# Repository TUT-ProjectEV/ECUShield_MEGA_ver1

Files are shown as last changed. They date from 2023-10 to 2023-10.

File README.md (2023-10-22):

# ECUShield_MEGA_ver1

## Overview
- メインECUのシールド
- 2023年度10月時点で使用

## Requirement
### Development
- Kicad 7.0
### Boards
- Arduino Mega
### Libraries

## Usage

## Features

## Reference
- [ECUShield_MEGA_ver1](https://github.com/ST04-tkmr/KicadProjects_EVProject/tree/main/ECUShield_MEGA_ver1) より

## Author
- Takamura
    - [GitHub](https://github.com/ST04-tkmr)

## License
- Copyright (c) 2023 東京工科大学 ProjectEV [Released under the MIT license](https://github.com/TUT-ProjectEV/ECUShield_MEGA_ver1/blob/main/LICENSE)

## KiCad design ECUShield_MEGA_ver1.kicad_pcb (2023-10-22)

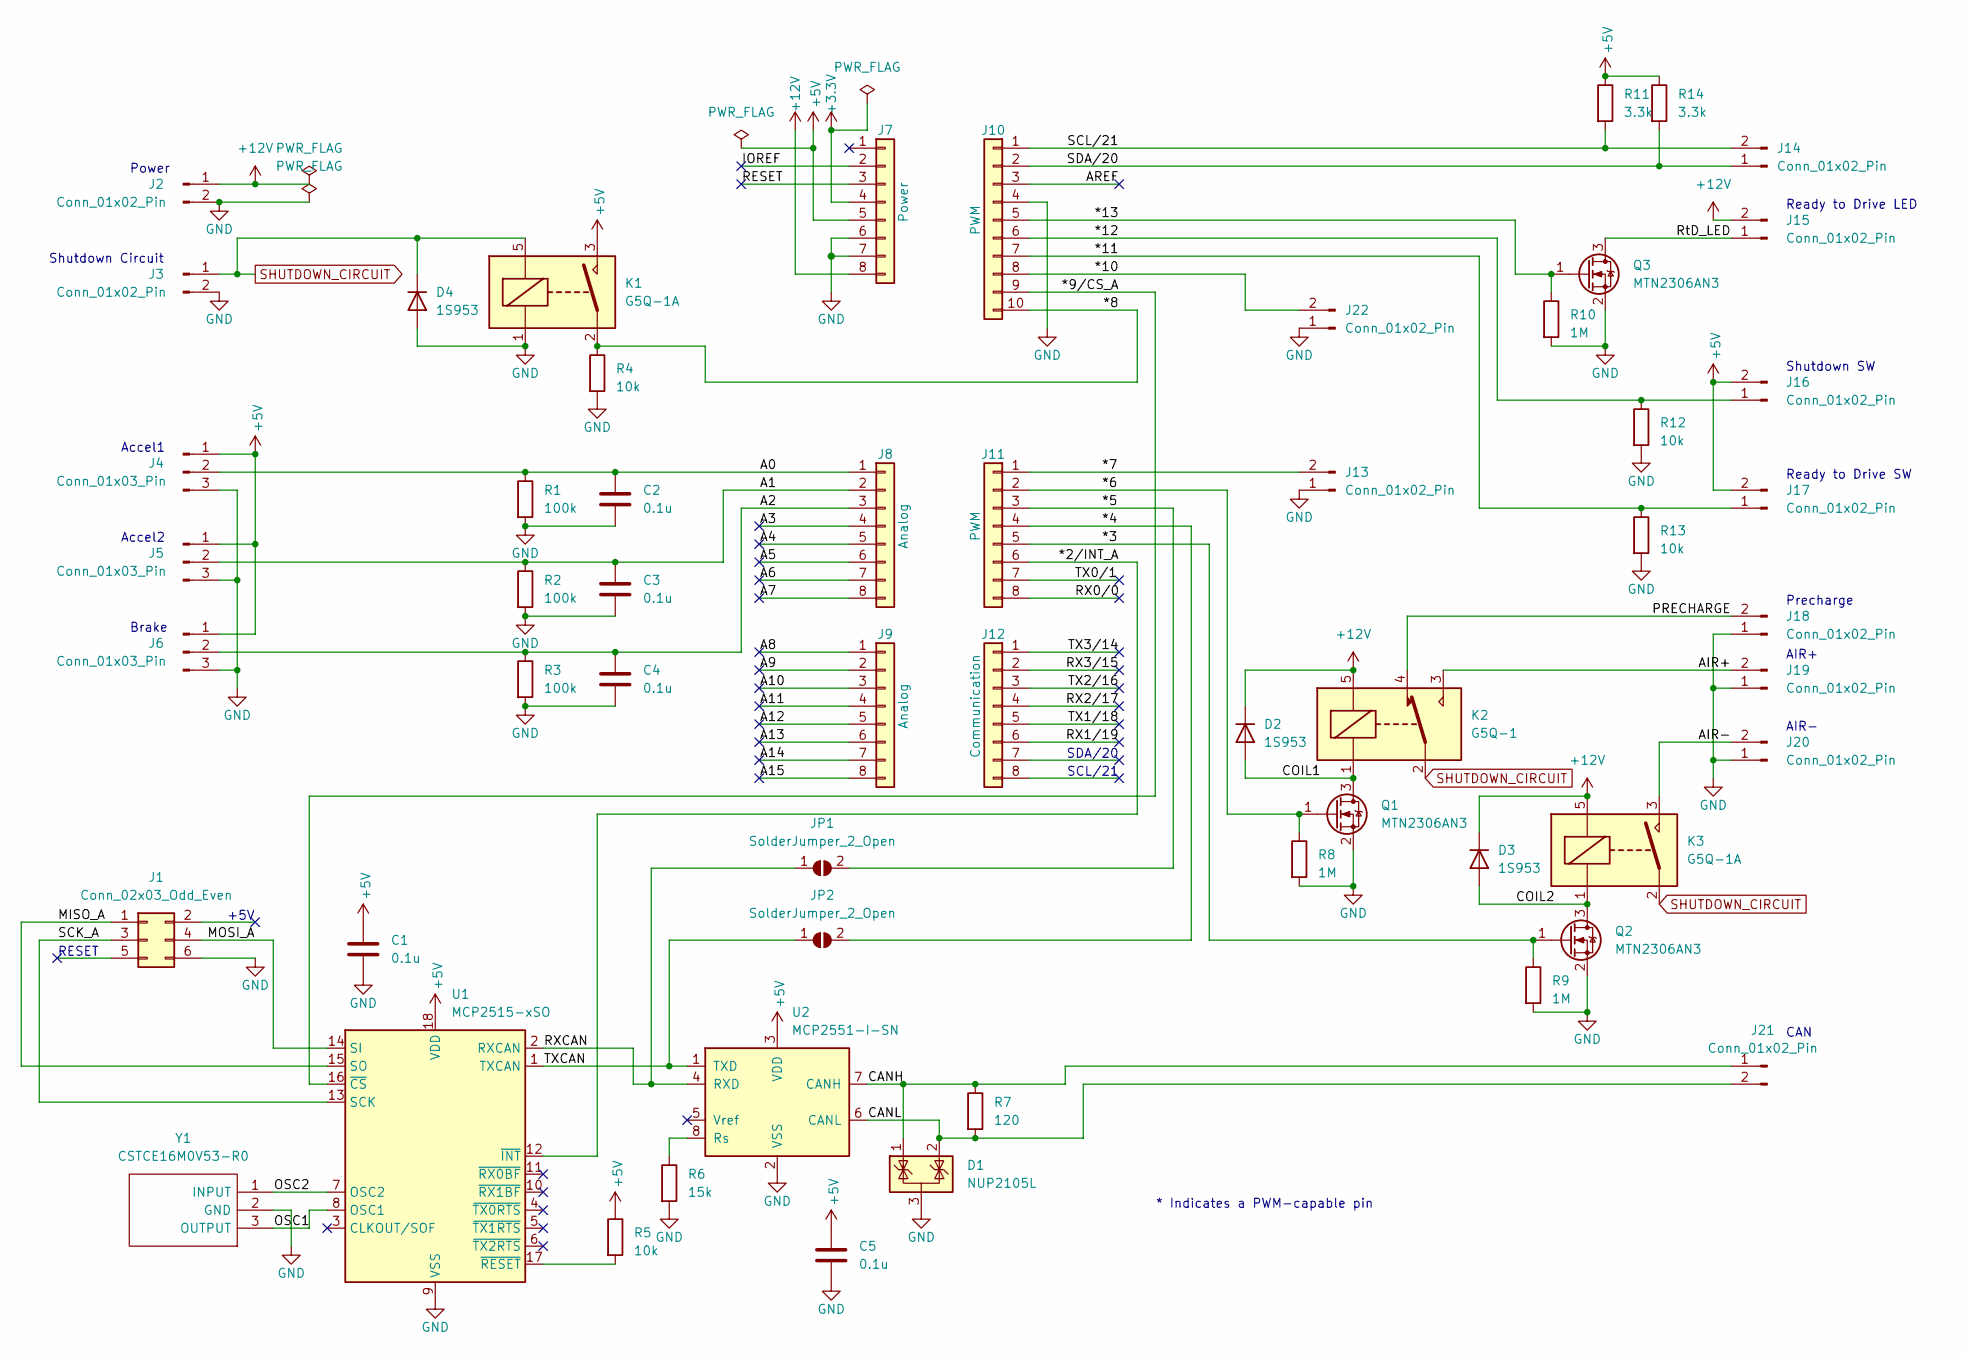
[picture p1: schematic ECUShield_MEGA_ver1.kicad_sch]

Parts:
C1, C2, C3, C4, C5: 0.1u; C_0603_1608Metric
D1: NUP2105L; SOT-23
D2, D3, D4: 1S953; D_DO-35_SOD27_P7.62mm_Horizontal
J1: Conn_02x03_Odd_Even; PinSocket_2x03_P2.54mm_Vertical
J2, J3, J13, J14, J15, J16, J17, J18, J19, J20, J21, J22: Conn_01x02_Pin; JST_XH_B2B-XH-A_1x02_P2.50mm_Vertical
J4, J5, J6: Conn_01x03_Pin; JST_XH_B3B-XH-A_1x03_P2.50mm_Vertical
J7: Power; PinSocket_1x08_P2.54mm_Vertical
J8, J9: Analog; PinSocket_1x08_P2.54mm_Vertical
J10: PWM; PinSocket_1x10_P2.54mm_Vertical
J11: PWM; PinSocket_1x08_P2.54mm_Vertical
J12: Communication; PinSocket_1x08_P2.54mm_Vertical
JP1, JP2: SolderJumper_2_Open; SolderJumper-2_P1.3mm_Open_RoundedPad1.0x1.5mm
K1, K3: G5Q-1A; Relay_SPST_Omron-G5Q-1A
K2: G5Q-1; Relay_SPDT_Omron-G5Q-1
Q1, Q2, Q3: MTN2306AN3; TSOT-23
R1, R2, R3: 100k; R_0603_1608Metric
R4, R5, R12, R13: 10k; R_0805_2012Metric
R6: 15k; R_0603_1608Metric
R7: 120; R_0603_1608Metric
R8, R9, R10: 1M; R_0603_1608Metric
R11, R14: 3.3k; R_0603_1608Metric
U1: MCP2515-xSO; SOIC-18W_7.5x11.6mm_P1.27mm
U2: MCP2551-I-SN; SOIC-8_3.9x4.9mm_P1.27mm
Y1: CSTCE16M0V53-R0; CSTCE16M0V53R0; Manufacturer_Part_Number CSTCE16M0V53-R0; Mouser Part Number 81-CSTCE16M0V53-R0

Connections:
+3.3V: J7.4
+5V: C1.1, C5.1, J4.1, J5.1, J6.1, J7.5, J16.2, J17.2, K1.3, R5.1, R11.1, R14.1, U1.18 (VDD), U2.3 (VDD)
+12V: D2.1 (K), D3.1 (K), J2.1, J7.8, J15.2, K2.5, K3.5
/*2/INT_A: J11.6, U1.12 (~INT)
/*3: J11.5, Q2.1 (G), R9.1
/*4: J11.4, JP2.2 (B)
/*5: J11.3, JP1.2 (B)
/*6: J11.2, Q1.1 (G), R8.1
/*7: J11.1, J13.2
/*8: J10.10, K1.2, R4.1
/*9/CS_A: J10.9, U1.16 (~CS)
/*10: J10.8, J22.2
/*11: J10.7, J17.1, R13.1
/*12: J10.6, J16.1, R12.1
/*13: J10.5, Q3.1 (G), R10.1
/A0: C2.1, J4.2, J8.1, R1.1
/A1: C3.1, J5.2, J8.2, R2.1
/A2: C4.1, J6.2, J8.3, R3.1
/A3: J8.4
/A4: J8.5
/A5: J8.6
/A6: J8.7
/A7: J8.8
/A8: J9.1
/A9: J9.2
/A10: J9.3
/A11: J9.4
/A12: J9.5
/A13: J9.6
/A14: J9.7
/A15: J9.8
/AIR+: J19.2, K2.3
/AIR-: J20.2, K3.3
/AREF: J10.3
/CANH: D1.1 (K), J21.1, R7.1, U2.7 (CANH)
/CANL: D1.2 (K), J21.2, R7.2, U2.6 (CANL)
/COIL1: D2.2 (A), K2.1, Q1.3 (D)
/COIL2: D3.2 (A), K3.1, Q2.3 (D)
/IOREF: J7.2
/MISO_A: J1.1, U1.15 (SO)
/MOSI_A: J1.4, U1.14 (SI)
/OSC1: U1.8 (OSC1), Y1.3 (OUTPUT)
/OSC2: U1.7 (OSC2), Y1.1 (INPUT)
/PRECHARGE: J18.2, K2.4
/RESET: J7.3
/RX0/0: J11.8
/RX1/19: J12.6
/RX2/17: J12.4
/RX3/15: J12.2
/RXCAN: JP1.1 (A), U1.2 (RXCAN), U2.4 (RXD)
/RtD_LED: J15.1, Q3.3 (D)
/SCK_A: J1.3, U1.13 (SCK)
/SCL/21: J10.1, J14.2, R11.2
/SDA/20: J10.2, J14.1, R14.2
/TX0/1: J11.7
/TX1/18: J12.5
/TX2/16: J12.3
/TX3/14: J12.1
/TXCAN: JP2.1 (A), U1.1 (TXCAN), U2.1 (TXD)
GND: C1.2, C2.2, C3.2, C4.2, C5.2, D1.3 (A), D4.2 (A), J1.6, J2.2, J3.2, J4.3, J5.3, J6.3, J7.6, J7.7, J10.4, J13.1, J18.1, J19.1, J20.1, J22.1, K1.1, Q1.2 (S), Q2.2 (S), Q3.2 (S), R1.2, R2.2, R3.2, R4.2, R6.2, R8.2, R9.2, R10.2, R12.2, R13.2, U1.9 (VSS), U2.2 (VSS), Y1.2 (GND)
unnamed: R5.2, U1.17 (~RESET)
unnamed: R6.1, U2.8 (Rs)
SHUTDOWN_CIRCUIT: D4.1 (K), J3.1, K1.5, K2.2, K3.2

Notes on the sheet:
Precharge
Power
Accel2
Ready to Drive SW
+5V
CAN
AIR+
Accel1
SDA/20
SCL/21
Shutdown SW
AIR-
* Indicates a PWM-capable pin
Brake
Ready to Drive LED
RESET
Shutdown Circuit

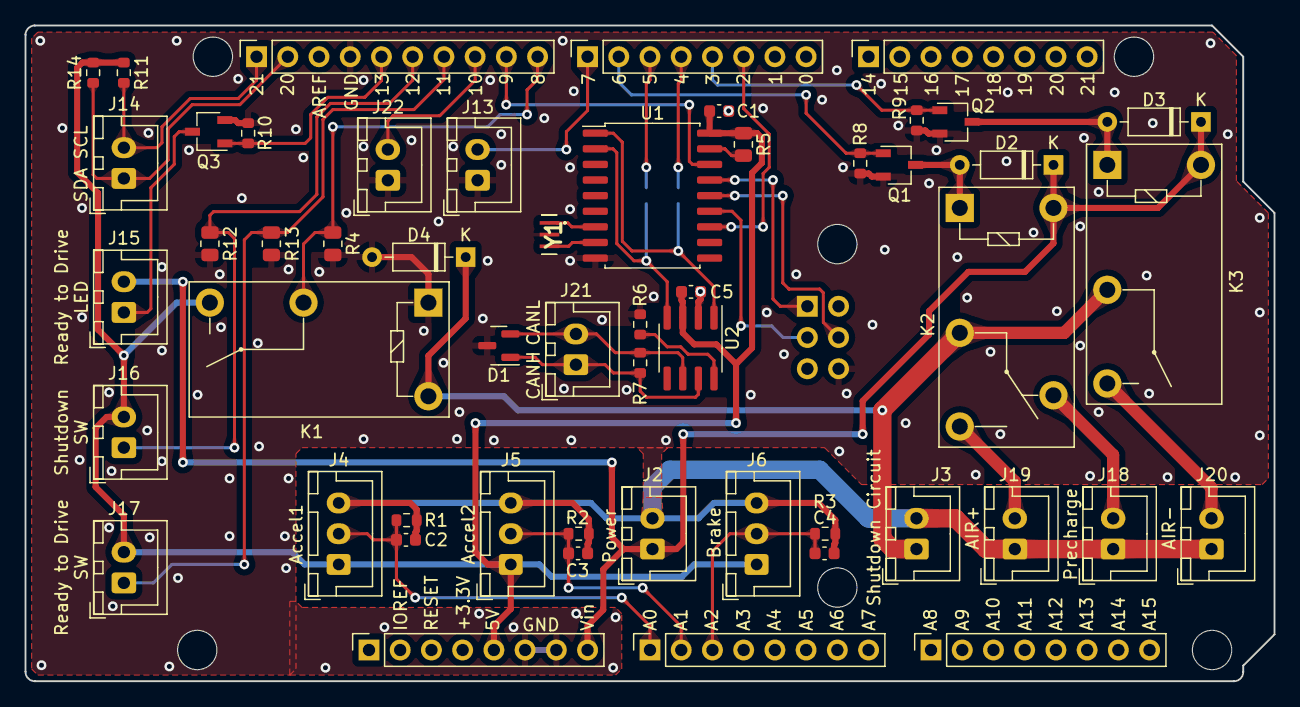
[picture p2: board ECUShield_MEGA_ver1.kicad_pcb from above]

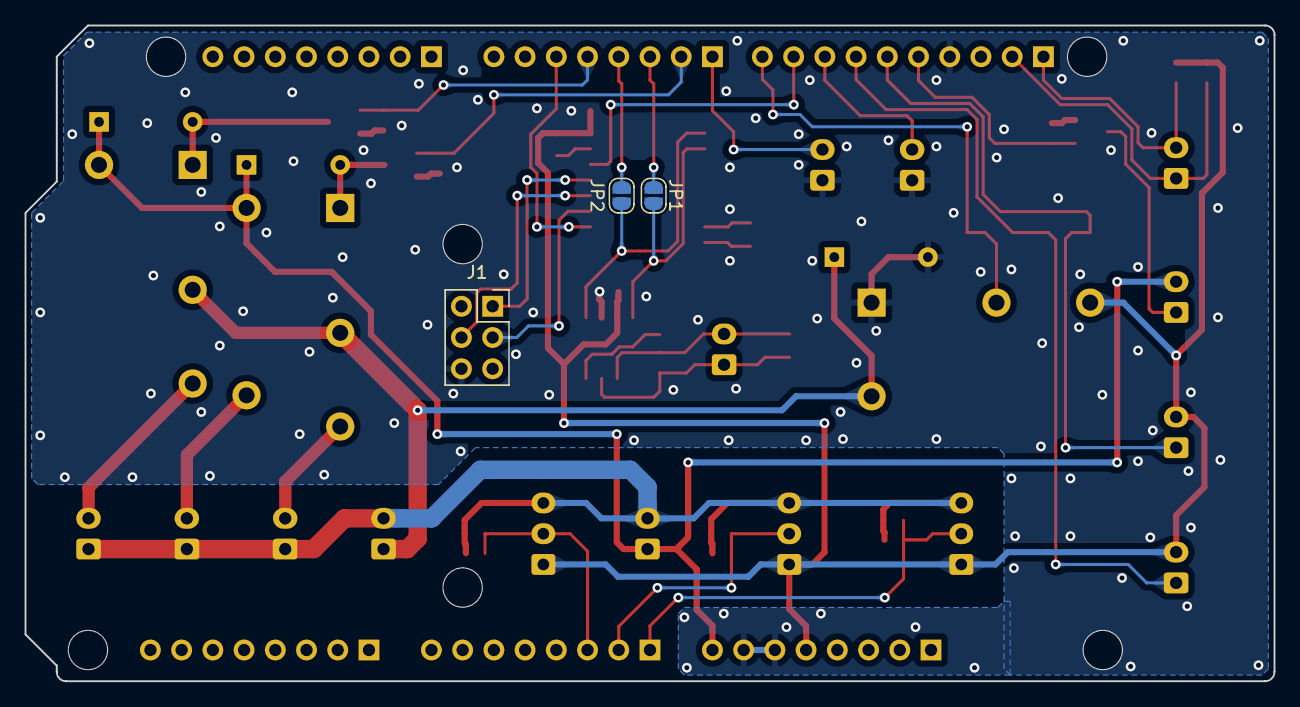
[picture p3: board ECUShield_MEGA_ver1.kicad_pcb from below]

Board: 2 copper layers, 101.6 x 53.3 mm, 62 parts (3 on the bottom side), 38 nets.

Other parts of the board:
MH1, MH2, MH3, MH4, MH5, MH6: MountingHole_3.2mm

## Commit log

2023-10-22 add project
    [ECUShield_MEGA_ver1.kicad_pcb, ECUShield_MEGA_ver1.kicad_sch]
2023-10-22 誤字修正
